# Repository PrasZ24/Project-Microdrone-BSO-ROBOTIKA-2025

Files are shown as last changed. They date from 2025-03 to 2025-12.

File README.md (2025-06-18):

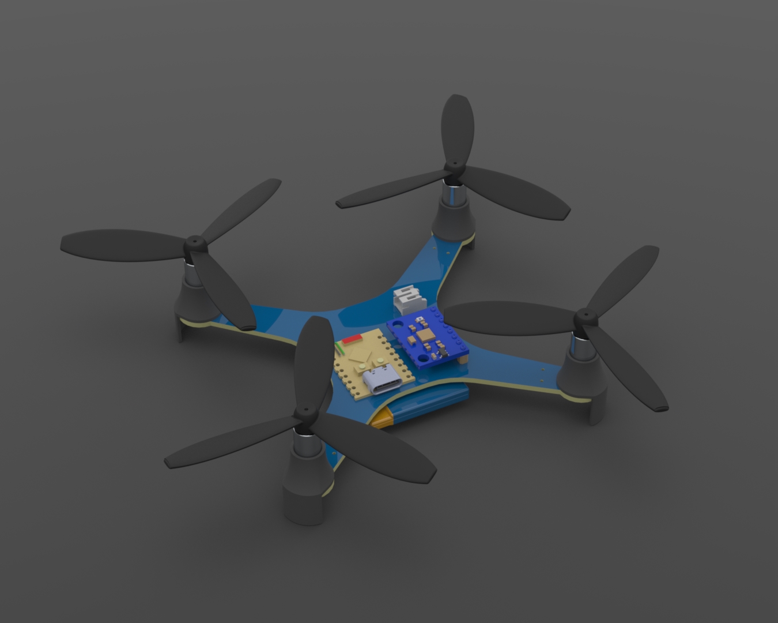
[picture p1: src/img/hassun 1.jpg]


# Project-AIRMINI (Aerial Intelligent Riset Microdrone Inovatif)-BSO-ROBOTIKA-2025
## Microdrone project by Research And Development BSO ROBOTIKA UIN Sunan Gunung Djati Bandung
Microdrone ini dirancang sebagai quadcopter compact dengan dimensi 130mm x 130mm, cocok untuk penerbangan rendah sekitar 10 meter di atas tanah. Dengan motor tipe "720" DC coreless, yang kecil dan efisien, dengan baling-baling yang bisa 2, 3, atau 4 bilah untuk fleksibilitas performa. Altitude diukur menggunakan sensor barometer, sementara stabilitas dikelola oleh IMU MPU6050, yang memastikan penerbangan stabil dengan kontrol PID, algoritma anti-windup, dan filter Kalman atau komplementer untuk data sensor yang akurat.

### Team list :
  - Prasetya Garda Kesumabangsa
  - Fikri Alif Hafiz
  - Muhammad Irsyad

Ini adalah repositori dari grup riset dan pengembangan BSO ROBOTIKA UIN Sunan Gunung Djati Bandung. Repositori ini akan berisikan catatan, hasil diskusi, code, desain mekanikal, desain elektrikal, skematik dan lain sebagainya dari hasil riset kami.

Status : Ongoing

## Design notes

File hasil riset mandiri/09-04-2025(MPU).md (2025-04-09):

**MPU-6050** itu adalah **sensor kecil** yang bisa mendeteksi:

1. **Gerakan (akselerasi)** – Misalnya seberapa cepat sensor itu digerakkan ke kiri, kanan, atas, atau bawah. MPU-6050 mengukur percepatan (bukan kecepatan).
2. **Putaran (rotasi/sudut)** – Misalnya kalo kita memiringkan atau memutar sensor ke arah tertentu.

Sensor ini penting untuk mikrodrone kita karena mikrodrone butuh tahu arah dan gerakan. Bisa dibilang ini kayak “indra keseimbangan” buat mikrodrone

Kalau digoyangin sensor ini, dia bisa tahu kamu gerakin ke mana, dan seberapa cepat gerakannya.

**catatan** : sensor MPU-6050 ini memiliki Sensor suhu, namun **bukan untuk mendeteksi suhu** lingkungan tetapi **f**ungsinya lebih ke mengkompensasi perubahan suhu internal sensor agar data akselerometer dan giroskop tetap akurat, karena sensor akselerator dan giroskop pada MPU-6050 itu sangat dipengaruhi oleh suhu.

Code membaca MPU6050 dengan Adafruit MPU6050: 

```arduino
// Basic demo for accelerometer readings from Adafruit MPU6050

#include <Adafruit_MPU6050.h>
#include <Adafruit_Sensor.h>
#include <Wire.h>

Adafruit_MPU6050 mpu;

void setup(void) {
  Serial.begin(115200);
  while (!Serial)
    delay(10); // will pause Zero, Leonardo, etc until serial console opens

  Serial.println("Adafruit MPU6050 test!");

  // Try to initialize!
  if (!mpu.begin()) {
    Serial.println("Failed to find MPU6050 chip");
    while (1) {
      delay(10);
    }
  }
  Serial.println("MPU6050 Found!");

  mpu.setAccelerometerRange(MPU6050_RANGE_8_G);
  Serial.print("Accelerometer range set to: ");
  switch (mpu.getAccelerometerRange()) {
  case MPU6050_RANGE_2_G:
    Serial.println("+-2G");
    break;
  case MPU6050_RANGE_4_G:
    Serial.println("+-4G");
    break;
  case MPU6050_RANGE_8_G:
    Serial.println("+-8G");
    break;
  case MPU6050_RANGE_16_G:
    Serial.println("+-16G");
    break;
  }
  mpu.setGyroRange(MPU6050_RANGE_500_DEG);
  Serial.print("Gyro range set to: ");
  switch (mpu.getGyroRange()) {
  case MPU6050_RANGE_250_DEG:
    Serial.println("+- 250 deg/s");
    break;
  case MPU6050_RANGE_500_DEG:
    Serial.println("+- 500 deg/s");
    break;
  case MPU6050_RANGE_1000_DEG:
    Serial.println("+- 1000 deg/s");
    break;
  case MPU6050_RANGE_2000_DEG:
    Serial.println("+- 2000 deg/s");
    break;
  }

  mpu.setFilterBandwidth(MPU6050_BAND_21_HZ);
  Serial.print("Filter bandwidth set to: ");
  switch (mpu.getFilterBandwidth()) {
  case MPU6050_BAND_260_HZ:
    Serial.println("260 Hz");
    break;
  case MPU6050_BAND_184_HZ:
    Serial.println("184 Hz");
    break;
  case MPU6050_BAND_94_HZ:
    Serial.println("94 Hz");
    break;
  case MPU6050_BAND_44_HZ:
    Serial.println("44 Hz");
    break;
  case MPU6050_BAND_21_HZ:
    Serial.println("21 Hz");
    break;
  case MPU6050_BAND_10_HZ:
    Serial.println("10 Hz");
    break;
  case MPU6050_BAND_5_HZ:
    Serial.println("5 Hz");
    break;
  }

  Serial.println("");
  delay(100);
}

void loop() {

  /* Get new sensor events with the readings */
  sensors_event_t a, g, temp;
  mpu.getEvent(&a, &g, &temp);

  /* Print out the values */
  Serial.print("Acceleration X: ");
  Serial.print(a.acceleration.x);
  Serial.print(", Y: ");
  Serial.print(a.acceleration.y);
  Serial.print(", Z: ");
  Serial.print(a.acceleration.z);
  Serial.println(" m/s^2");

  Serial.print("Rotation X: ");
  Serial.print(g.gyro.x);
  Serial.print(", Y: ");
  Serial.print(g.gyro.y);
  Serial.print(", Z: ");
  Serial.print(g.gyro.z);
  Serial.println(" rad/s");

  Serial.print("Temperature: ");
  Serial.print(temp.temperature);
  Serial.println(" degC");

  Serial.println("");
  delay(500);
}
```

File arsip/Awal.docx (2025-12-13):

- MCU = ESP32 C3 mini
- Micromotor DC = 720 ?
- Propoller = Menyusul
- Motor Driver = Mosfet
- Kontrol = Bluetooth / Wifi
- Sensor =

Sensor sudut : IMU MPU6050 -> MPU9250

Sensor ketinggian : Altitude (BMP 280) Sensor tekanan udara

- Chasis = PCB
- Baterai = lithium 3.7V

Motor driver dan regulator
IMU dan Barometer dan Filter
System Control
PID
Mekanis

Perakitan dan troubleshouting

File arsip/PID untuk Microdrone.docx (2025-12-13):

PID untuk Microdrone

Oleh : Departemen Riset dan Pengembangan ROBOTIKA UIN SGD

Microdrone berbeda dari drone biasanya dan justru lebih sulit untuk direalisasikan. Hal ini karena microdrone memiliki ukuran yang kecil, membatasi sumber daya yang dapat digunakan. Hal ini tentu saja berimbas pada kontroller yang digunakan pada drone. Perbedaan motor DC, propeller, panjang lengan, massa, baterai, serta titik keseimbangan drone akan mempengaruhi kontrol yang digunakan. Setidaknya, pada suatu drone dibutuhkan sebuah sistem kontrol PID.

A. Sistem Kontrol PID (Proportional-Integral-Derivate)

PID (Proportional-Integral-Derivative) adalah sebuah sistem kontrol yang bertujuan untuk mencapai sebuah setpoint (titik atau nilai yang ditentukan) secara cepat dengan menggunakan akumulasi dari propotional, integral dan derivative. Sistem kontrol PID merupakan sistem kontrol closed loop yang membutuhkan feedback (umpan balik) dari output. Pada drone, output yang digunakan merupakan pembacaan sensor gyroscope, accelerometer,dan Magnetometer yang akan dihitung menjadi sudut. Sehingga nantinya, output akan digunakan bersama dengan setpoint untuk menghitung nilai error yang akan menjadi umpan balik untuk sistem PID. Error dapat dihitung secara matematis dengan:

error(t)=setpoint(t)-output(t)

Error ini akan digunakan pada setiap komponen yang digunakan di PID dan error inilah yang memberitahu sistem apakah sistem sudah mencapai setpoint atau belum dan seberapa jauh kondisi sistem saat ini dengan setpoint yang diinginkan.

Agar lebih sistematis, PID dapat dibagi berdasarkan komponen-komponennya, yaitu:

a) Proportional (kesebandingan)

Merupakan komponen PID yang menghitung secara sebanding dengan nilai error dan konstanta atau gainnya. Secara matematis dapat dihitung:

proportional(t)=Gain_(Proportional) ×error(t)

Pada drone, proportional mengatur seberapa responsif drone terhadap error. Semakin besar gain proportional yang diberikan, semakin cepat drone menanggapi error. Dan semakin kecil gain proportional yang diberikan, drone akan semakin lambat menanggapi error. Nilai gain inilah yang akan diatur atau dituning sehingga menghasilkan perilaku drone yang tepat.

- Jika drone berosilasi terlalu cepat, berarti nilai gain nya terlalu besar.
- Jika drone tidak berosilasi atau bahkan tidak mampu mencapai setpoint, maka nilai gain nya terlalu kecil.
- Nilai gain yang baik adalah ketika drone berosilasi tidak terlalu cepat tetapi dapat mencapai (atau melebihi) setpoint. Terutama jika diberi gangguan.
b) Integral

Merupakan komponen PID yang mengakumulasi error statis pada drone yang tidak bisa diselesaikan oleh proportional. Misalnya, drone sudah berhasil stabil disudut 2° tetapi, karena nilai error tetap, proportional tidak dapat menambahkan atau mengurangi nilainya agar drone bisa mencapai sudut 0° (setpoint). Sehingga, integral diperlukan. Integral walaupun nilai errornya tetap, ia dapat bertambah terus nilainya seiring dengan waktu hingga drone mencapai setpoint. Secara matematis, integral dapat dituliskan :

integral(t)=Gain_(Integral) ×(∫_0^t error(τ) dτ)

Dalam rumus diatas variabel t menunjukkan waktu sekarang (saat ini), sedangkan τ hanyalah variabel untuk integrasi. Integral pada PID ditulis seperti pada persamaan diatas karena kita ingin menjumlahkan error dari waktu nol hingga waktu t, dan untuk menghindari kebingungan digunakan simbol τ sebagai penanda waktu yang “berjalan” di dalam integral, sementara t tetap dipakai sebagai batas atas (waktu sekarang).

Pada drone, jika semakin besar gainnya, error statis akan cepat hilang. Namun jika semakin kecil gainnya, error statis akan sulit hilang.

- Jika drone malah berosilasi, berarti nilai gain integral terlalu besar.
- Jika drone terlalu lambat untuk menghilangkan error statis atau mencapai setpoint, maka nilai gain integral terlalu kecil.
- Nilai gain integral yang baik adalah ketika sistem dapat menghilangkan error statis tanpa terjadi overshoot.
c) Derivative (turunan)

Merupakan komponen PID yang melihat seberapa cepat error berubah terhadap waktu dengan memafaatkan penurunan error terhadap waktu. Secara matematis dapat ditulis:

derivative(t)=Gain_(Derivative) ×(error(t)d/(dt))

Pada drone, derivative dapat mengatur atau meredam osilasi. Derivative dapat bertindak sebagai “rem” ketika drone sudah dekat dengan setpoint. Jika error berubah cepat (misalnya output sistem mendekati setpoint dengan laju tinggi), maka komponen derivative akan menghasilkan sinyal besar untuk mengurangi kecepatan perubahan tersebut. Namun, jika error berubah lambat atau konstan, komponen derivative hampir tidak memberikan kontribusi.

- Jika drone jadi tidak responsif, berarti nilai gain derivative terlalu besar.
- Jika drone tetap berosilasi kencang, berarti nilai gain derivative terlalu kecil.
- Nilai gain derivative yang tepat adalah ketika drone dapat merespon gangguan dan drone dapat stabil tanpa osilasi.

Sebagaimana yang disebutkan sebelumnya, PID adalah akumulasi dari komponen proportional, integral dan derivative. Sehingga, output dari masing-masing komponen tersebut dijumlahkan menjadi satu output. Secara matematis dapat ditulis sebagai berikut :

PID(t)=proportional(t)+integral(t)+derivative(t)

Output pid ini dapat langsung digunakan untuk mengontrol aktuator. Pada drone, output pid dapat langsung digunakan sebagai nilai PWM dan disesuaikan dengan kondisi drone. Tetapi, output PID ini hanya bisa digunakan untuk 1 axis saja. Sehingga jika ingin menstabilkan di 3 axis diperlukan 3 sistem kontrol PID.

Pada percobaan yang kami lakukan, sayangnya PID saja tidak cukup. Khususnya pada microdrone dengan panjang lengan yang relatif pendek. Lengan yang pendek ini menyebabkan momen inersia pada microdrone menjadi lebih kecil dan tidak memiliki keseimbangan “alami”.Hal ini mengakibatkan drone menjadi lebih agresif dan sulit untuk “tenang”. Sehingga, untuk mengatasi masalah tersebut, digunakan sistem kontrol PID yang lebih modern. Yaitu cascade PID.

B. Sistem Kontrol Cascade PID (PID Berurut)

Pada dasarnya cascade PID adalah loop PID biasa yang ditumpuk dua atau lebih secara berurut. Misalnya pada sistem paling sederhana dari cascade PID dengan dua loop saja. Yaiut outer loop dan inner loop. Dimana output dari outer loop akan menjadi setpoint dari inner loop. Cascade PID ini Lebih cepat merespons gangguan karena inner loop bisa mengoreksi lebih dulu sebelum error besar muncul di variabel utama atau di outer loop. Serta menjamin stabilitas yang lebih baik untuk sistem kompleks yang punya variabel turunan, noise yang tinggi, dan sistem yang sensitif atau agresif. Secara matematis, persamaan PID baik inner loop maupun outer loop sama. Yang membedakan ada pada nilai errornya. Error pada inner loop dihitung dengan :

error_(inner loop) (t)= output_(outer loop) (t)-

output_(inner loop) (t)

Barulah pada PID inner loop, outputnya digunakan untuk mengatur/mengontrol aktuator.

Pada drone, outer loop menggunakan umpan balik dari sudut atau kemiringan drone. Sedangkan untuk inner loopnya, menggunakan umpan balik dari kecepatan sudut drone. Sehingga, inner loop akan bereaksi sesuai dengan kecepatan perubahan sudut. Jika drone bergerak dari sudut 0° ke 30° dengan cepat, maka error pada inner loop akan besar juga. Memperbesar nilai output dan mengatasi perubahan cepat atau perubahan yang agresif dari drone. Sedangkan ketika perubahan sudut drone lambat, maka nilai error inner loop nya relatif lebih kecil, memungkinkan hanya output dari outer loop yang bekerja.

- Outer loop berfungsi untuk “mengejar” nilai setpoint.
- Inner loop berfungsi untuk mengatasi drone yang agresif sehingga outer loop dapat bekerja dengan lebih baik.
C. Penerapan PID pada program

Penerapan PID untuk microdrone ini dilakukan pada ESP32 C3 sehingga bahasa yang digunakan adalah CPP atau arduino. Sedangkan pada bahasa CPP tidak ada operasi integral ataupun turunan secara langsung. Tidak seperti pada Matlab ataupun python. Sehingga integral dan turunan dihitung dengan pendekatan diskrit. Untuk integral dapat menggunakan pendekatan dengan Euler Forward dan untuk turunannya menggunakan Backward Difference. Berikut cuplikan kodenya untuk PID Cascade pada axis roll :

// ===== Outer Loop (Angle PID) =====

double error_angle_roll, prevError_angle_roll = 0;

double integral_angle_roll = 0;

double kp_angle_roll = 5, ki_angle_roll = 0.001, kd_angle_roll = 0.01;

unsigned long lastTime_angle_roll;

float sampleTime_angle = 0.01; // 100 Hz

float rateTarget_roll = 0; // output → target laju (°/s)

// ===== Inner Loop (Rate PID) =====

double error_rate_roll, prevError_rate_roll = 0;

double integral_rate_roll = 0;

double kp_rate_roll = 1, ki_rate_roll = 0.01, kd_rate_roll = 0.04;

unsigned long lastTime_rate_roll;

float sampleTime_rate = 0.002; // 500 Hz

double integral_limit = 30; // batas integral anti-windup

// ===== Outer Loop: Angle Control =====

float hitungPIDAngleRoll(float angleY) {

unsigned long now = millis();

float dt = (now - lastTime_angle_roll) / 1000.0;

if (dt >= sampleTime_angle) {

float error = setPoint_roll - angleY;

float P = kp_angle_roll * error;

integral_angle_roll += error * dt;

// Anti-windup

if (integral_angle_roll > integral_limit) integral_angle_roll = integral_limit;

if (integral_angle_roll < -integral_limit) integral_angle_roll = -integral_limit;

float I = ki_angle_roll * integral_angle_roll;

float D = kd_angle_roll * ((error - prevError_angle_roll) / dt);

rateTarget_roll = P + I + D;

// Batas rate target

if (rateTarget_roll > 200) rateTarget_roll = 200;

if (rateTarget_roll < -200) rateTarget_roll = -200;

prevError_angle_roll = error;

lastTime_angle_roll = now;

}

return rateTarget_roll;

}

// ===== Inner Loop: Rate Control =====

void hitungPIDRateRoll(float gyroY, float rateTarget_roll) {

unsigned long now = millis();

float dt = (now - lastTime_rate_roll) / 1000.0;

if (dt >= sampleTime_rate) {

float error = rateTarget_roll - gyroY;

float P = kp_rate_roll * error;

integral_rate_roll += error * dt;

// Anti-windup

if (integral_rate_roll > integral_limit) integral_rate_roll = integral_limit;

if (integral_rate_roll < -integral_limit) integral_rate_roll = -integral_limit;

float I = ki_rate_roll * integral_rate_roll;

float D = kd_rate_roll * ((error - prevError_rate_roll) / dt);

pwmOut_roll = P + I + D;

if (pwmOut_roll > 200) pwmOut_roll = 200;

if (pwmOut_roll < -200) pwmOut_roll = -200;

prevError_rate_roll = error;

lastTime_rate_roll = now;

}

Agar lebih jelas, program akan dibahas perbaris.

// ===== Outer Loop: Angle Control =====

float hitungPIDAngleRoll(float angleY) {

Sintaks untuk membuat sebuah fungsi yang menghitung PID bagian outer loop atau yang menghitung dengan setpoint dari pengguna (dalam derajat) dan umpan balik sudut. Parameter didalam adalah untuk memasukan umpan balik sudut.

unsigned long now = millis();

Membuat variabel lokal bernama now dengan tipe data long. Unsigned menunjukan bahwa variabel tidak menerima data negatif. Kemudian variabel ini diisi oleh RTC dari ESP32 atau dapat dipanggil dengan fungsi millis(). Millis ini bekerja dengan menghitung seberapa lama (dalam mili detik) ESP32 menyala terhitung dari pertama kali dinyalakan.

float dt = (now - lastTime_angle_roll) /

1000.0;

Variabel dt dengan tipe data float adalah variabel yang menghitung jarak waktu antar loop per satuan detik. Variabel ini penting digunakan untuk integral maupun turunan.

if (dt >= sampleTime_angle) {

Pengkondisian untuk mengatur seberapa cepat loop setiap perhitungan PID nya atau bisa disebut sample rate nya. Nilai sampleTime dapat diatur tetapi direkomendasikan di 100Hz atau 0.001.

float error = setPoint_roll - angleY;

Menghitung nilai error dengan set point dan sudut.

float P = kp_angle_roll * error;

Menghitung komponen PID yang pertama yaitu proportional sesuai dengan yang ada pada rumus umumnya.

integral_angle_roll += error * dt;

Menghitung integral (bukan hasil akhir) dengan Euler Forward. Dimana agar variabel integral_angle_roll tidak kembali ke nilai 0 atau reset, maka variabel tersebut harus dideklarasikan sebagai variabel global. Hal ini penting karena pada pendekatan Euler Forward, menggunakan persamaan :

integral(t)=integral(t-1)+error(t)*dt

Pada rumus tersebut, dibutuhkan nilai integral sebelumnya. Sehingga nilai integral sebelumnya harus tetap ada. Selain itu, pada Euler Forward nilai error saat ini dkalikan dengan waktu sampling antar loop dan ditambahkan nilai integral sebelumnya.

if (integral_angle_roll > integral_limit)

integral_angle_roll = integral_limit;

Pengkondisian untuk logika anti-wind up integral. Logika ini berfungsi untuk membatasi nilai integral. Karena nilai integral terikat pada nilai sebelumnya, sehingga jika tidak dibatasi oleh variabel integral_limit maka nantinya nilai integral akan menjadi terlalu besar dan akan sulit untuk turun lagi jika ada perubahan yang mendadak dan cepat. Pada kondisi ini, jika nilai integralnya melebihi dari batas yang diterapkan, program akan memberikan nilai batasnya ke variabel integral.

if (integral_angle_roll < -

integral_limit) integral_angle_roll = -integral_limit;

Baris ini adalah pengkondisian untuk logika anti-wind up integral juga. Tetapi untuk bagian negatifnya atau ketika perhitungan integral menghasilkan negatif tetap harus dibatasi.

float I = ki_angle_roll *

integral_angle_roll;

Menghitung nilai integral yang dikalikan dengan gain dari integral.

float D = kd_angle_roll * ((error –

prevError_angle_roll) / dt);

Menghitung komponen terakhir pada PID yaitu derivative atau turunan menggunakan Backward Different. Turunan ini dihitung dengan persamaan :

derivative(t)=(error(t)-error(t-1))/(dt)

Dimana, setelah rumus diatas dihitung. Hasilnya dikalikan dengan gain dari derivative untuk tuningnya.

rateTarget_roll = P + I + D;

Sesuai dengan rumus umum, komponen-komponen PID dijumlahkan dan karena ini adalah outer loop. Maka outputnya dianggap sebagai setpoint untuk inner loop atau rate target.

if (rateTarget_roll > 200)

rateTarget_roll = 200;

Pengkondisian untuk membatasi output dari PID agar tidak terlalu besar dan mengganggu throttle. Pada contoh ini menggunakan PWM dengan resolusi 8 bit atau dari 0 hingga 255. Sehingga agar terdapat “nafas” untuk throttle output PID dibatasi hingga 200 atau dapat disesuaikan tergantung kondisi dari drone.

Walaupun pada outer loop outputnya digunakan untuk setpoint inner loop, tetap harus dibatasi. Mengingat setpoint memiliki peran yang besar dalam menentukan error.

if (rateTarget_roll < -200)

rateTarget_roll = -200;

Pengkondisian untuk membatasi output PID outer loop yang membatasi bagian negatif jika output yang dikeluarkan oleh perhitungan menghasilkan nilai negatif.

prevError_angle_roll = error;

Variabel yang berfungsi menyimpan nilai error sebelumnya. Variabel ini harus dideklarasikan sebagai variabel global agar nilainya tidak kembali ke nilai default.

lastTime_angle_roll = now;

Variabel yang menyimpan nilai waktu setelah perhitungan PID selesai. Variabel ini juga harus dideklarasikan sebagai variabel global. Bagian ini digunakan dalam perhitungan dt.

return rateTarget_roll;

Karena fungsi didefinisikan sebagai fungsi bertipe float. Sehingga perlu ada nilai yang dikembalikan. Sehingga sebagai output atau pengembalian yang diharapkan dari fungsi ini adalah output akhir dari PID. Selain itu, dengan menggunakan pengembalian seperti ini memungkinkan fungsi dijalankan dalam parameter fungsi lain. Seperti pada fungsi inner loop nanti.

// ===== Inner Loop: Rate Control =====

void hitungPIDRateRoll(float gyroY, float rateTarget_roll) {

Mendefinisikan sebuah fungsi untuk menghitung PID pada inner loop. Didalamnya ada parameter untuk umpan balik yang menggunakan gyro pada axis roll dan parameter untuk setpoint dari perhitungan outer PID sebelumnya.

Untuk bagian perhitungan PID lainnya sama saja. Namun, perhitungan errornya menggunakan setpoint dari output outer loop dan menggunakan data dari pembacaan sensor gyroscope dan bukan sudut.

Selain itu, yang membedakan fungsi pada inner loop dengan outer loop adalah pada akhir fungsi. Dimana karena inner loop bertipe void, maka tidak ada nilai yang dikembalikan. Dan output PID akhir tersimpan di variabel global dan siap digunakan.

Walaupun PID pada dasarnya adalah sistem kontrol yang paling umum digunakan untuk menstabilkan drone, pada kasus-kasus tertentu khususnya pada microdrone PID saja tidak cukup. Dibutuhkan sistem kontrol cascade PID yang memiliki kinerja lebih baik karena menggunakan dua PID secara berurutan.

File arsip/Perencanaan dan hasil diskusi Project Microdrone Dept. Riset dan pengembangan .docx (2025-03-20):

Rev 1.0

10/05/25

Rev 1.1

13/05/25

Identifikasi Kebutuhan

- Drone quadcopter;
- Terbang dengan ketinggian rendah dan stabil;
- Kontrol NRF24l01 SMD atau bluetooth;
- Penggunaan komponen seminim dan sesederhana mungkin;

Analisis Kebutuhan

- Drone quadcopter, dimensi maksimal 130mm x 130mm. Dengan 4 micromotor dc 720, propeller 4, 3 atau 2 bilah dan baterai lithium (menyesuaikan).
- Terbang dengan ketinggian rendah, yaitu sekitar 10m diatas permukaan tanah. Ketinggian drone diketahui dengan sensor barometer[1]. Dan stabilitas drone diatur menggunakan IMU MPU6050[2].
- Menerapkan PID, anti windup algorithm, dan kalman atau complementary filter.
- Kontrol drone dikendalikan oleh manusia (manual). Baik menggunakan remote control nrf24l01 atau remote control berbasis bluetooth (misal ps3).
- Untuk mencapai ukuran yang seminim mungkin dan desain yang kompleks. Dibutuhkan komponen-komponen SMD. Untuk regulator dan mosfet membutuhkan arus maksimal yang besar (diatas 2.5A).

Apa saja yang dibutuhkan untuk membangun drone?

- MCU = ESP32 C3 mini
- Micromotor DC = 720 ?
- Propoller = Menyusul
- Motor Driver = Mosfet
- Kontrol = Bluetooth / Wifi
- Sensor =

Sensor sudut : IMU MPU6050 -> MPU9250

Sensor ketinggian : Altitude (BMP 280) Sensor tekanan udara

- Chasis = PCB
- Baterai = lithium 3.7V

Alur riset :

- Motor driver dan regulator
- System Control (Remote Control)
- Dasar-dasar PID
- Data processing : IMU dan Barometer serta Filter nya
- Mekanikal
- Perancangan, Perakitan dan troubleshouting

Ref :

[1] https://www.hackster.io/SurtrTech/bmp280-measure-temperature-pressure-and-altitude-e1c857

[2] https://electronoobs.com/eng_robotica_tut9_2_2.php

[3] https://docs.espressif.com/projects/espressif-esp-drone/en/latest/gettingstarted.html

[4] https://youtu.be/dMRDzicSvXk?si=LSDi5mkgHMitzkxS

[5] https://www.youtube.com/watch?v=Sa6EslOHsI0&t=210s

[6] Muhammad Dzaki Al Haidar, Elshinta Adelia Ryzty, Rizky Ramadhan,Theodorich Brian Putra Marpaung, Ariq Rifki Kurniawan, Ardy Seto Priambodo. “Pengembangan Mini Drone Berbasis ESP32 dengan Roll dan Pitch ControlMenggunakan Algoritma PID.” Daerah Istimewa Yogyakarta, vol. 18, https://electrician.unila.ac.id/index.php/ojs/article/view/2597/559.

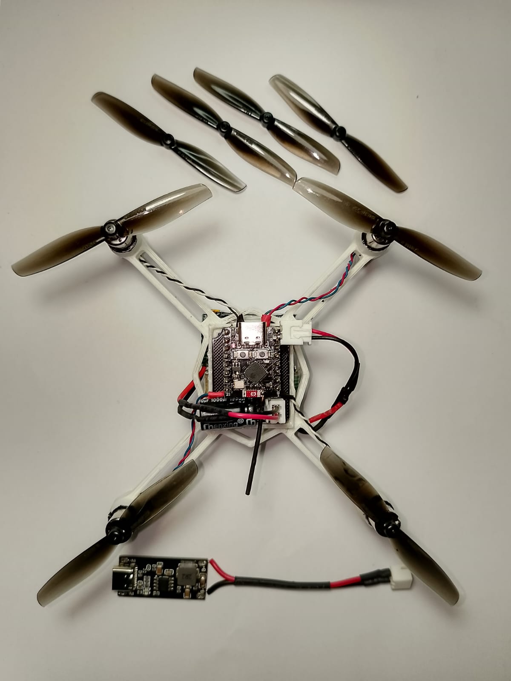
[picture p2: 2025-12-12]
dokumentasi/IMG-20251211-WA0007.jpg

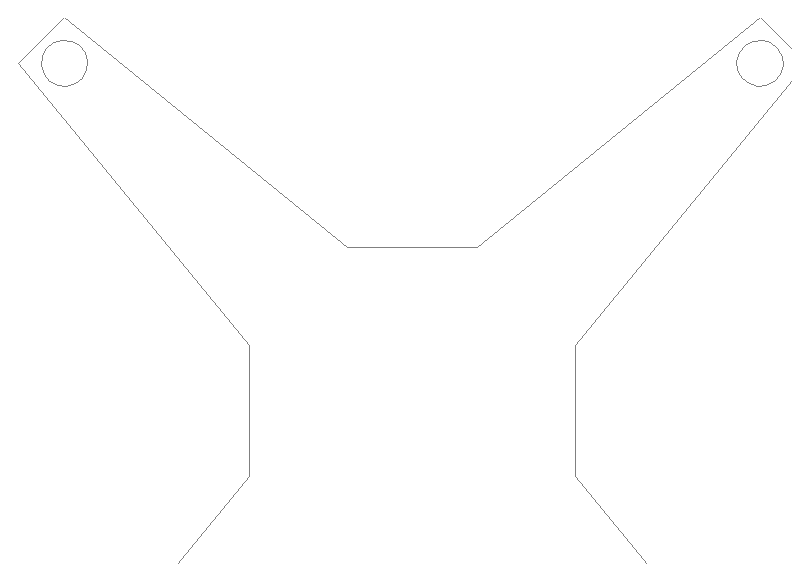
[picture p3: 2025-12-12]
arsip/3d and file/Drone_pcb.PNG

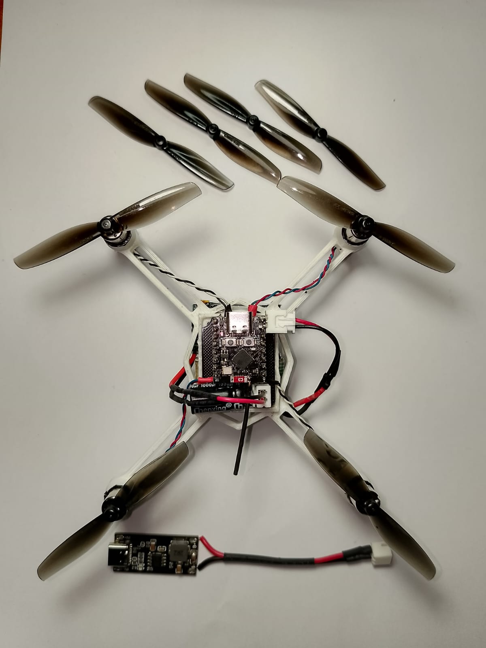
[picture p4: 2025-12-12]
dokumentasi/IMG-20251211-WA0010.jpg

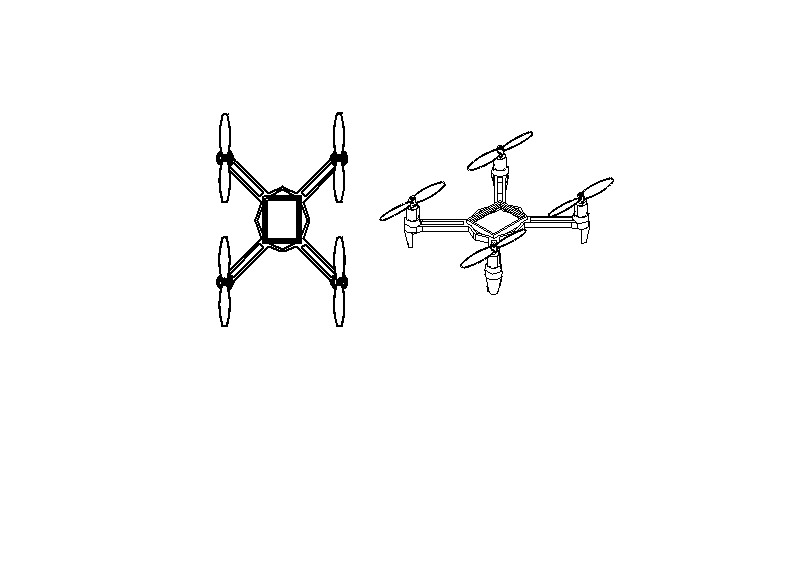
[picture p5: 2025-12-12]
arsip/3d and file/drone3.JPG

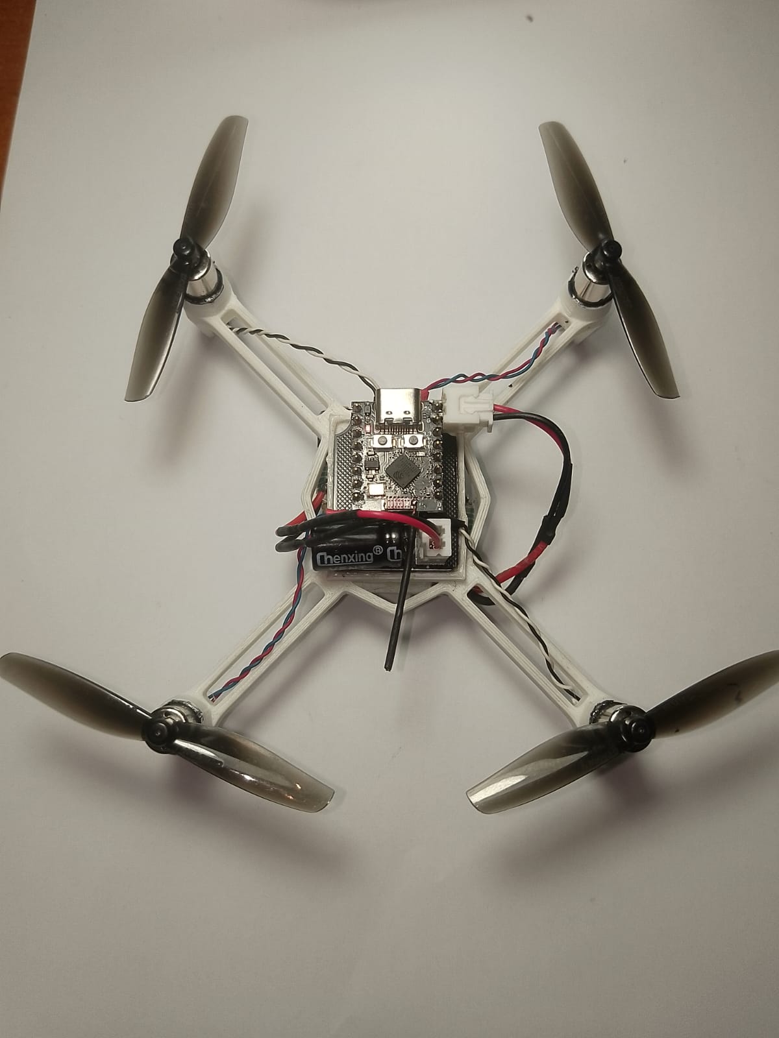
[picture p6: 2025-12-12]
dokumentasi/IMG-20251211-WA0008.jpg

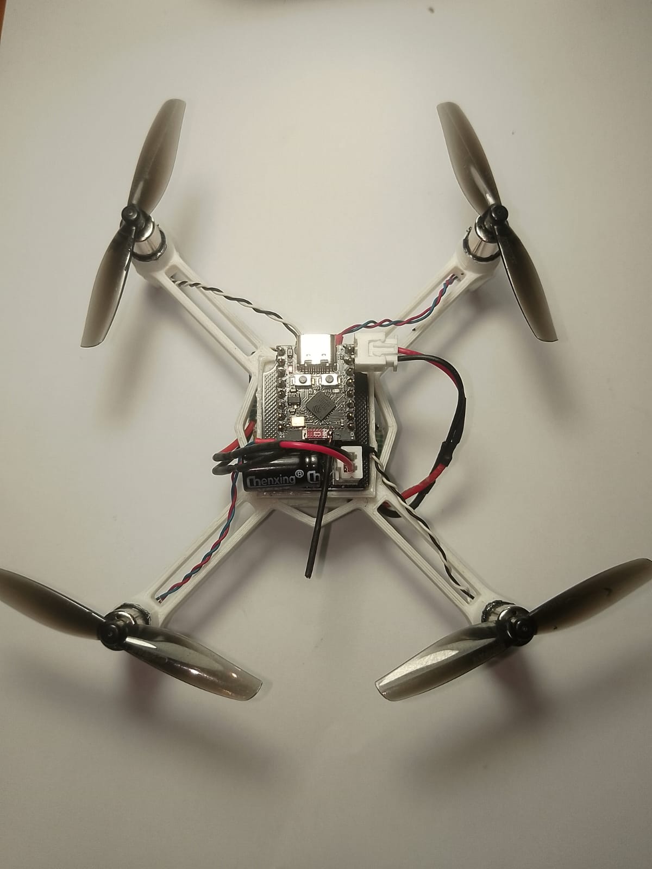
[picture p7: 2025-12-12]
dokumentasi/IMG-20251211-WA0009.jpg

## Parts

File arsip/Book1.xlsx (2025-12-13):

No | Nama | qty | harga | total | link
1 | Micromotor 716 | 4 | Rp 12000.00 | Rp 48000.00 | https://shopee.co.id/Hollow-Cup-Motor-Dinamo-Pesawat-Drone-Helikopter-7mm-714-716-720-i.53753550.21281371067
2 | Baterai | 1 | Rp 150000.00 | Rp 150000.00 | https://shopee.co.id/Gaoneng-GNB-2S-850mah-60C-120C-LiHV-Battery-7.6V-Socket-XT30-i.21348567.25813407479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
3 | propeller | 1 | Rp 40000.00 | Rp 40000.00 | https://shopee.co.id/product/991860709/28727072370?d_id=f3d39&uls_trackid=53qdgslt00rn
4 | Charger | 1 | Rp 40000.00 | Rp 40000.00
5 | 3d print chasis | 1 | Rp 20000.00 | Rp 20000.00
Total |  |  |  | Rp 298000.00

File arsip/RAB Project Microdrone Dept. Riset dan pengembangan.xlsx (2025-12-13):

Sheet: RAB Batch 1
RAB Project Microdrone
No. | Nama @jumlah | Harga | Link
1 | ESP32 C3 Super Mini @1 | Rp 48000.00 | esp32 (https://shopee.co.id/ESP32-C3-RISC-V-Super-Mini-Development-Board-WiFi-Bluetooth-5.0-ESP8266-Type-C-i.65450634.28022146930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) | Rp 163000.00 | Tidak dibeli
2 | MPU9250 + bmp280 @1 | Rp 115000.00 | MPU9250+BMP280 (https://shopee.co.id/(Ready-Stock)-GY-91-MPU9250-BMP280-10DOF-Acceleration-Gyroscope-Compass-Altimeter-Altitude-9-Axis-Sensor-Module-i.1385560436.28870693350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) |  | Dibeli
3 | Micromotor 720 @4 | Rp 40000.00 | 720 (https://www.tokopedia.com/cncstorebandung/micro-small-motor-dc-720-46000rpm-3-7v-high-torque-for-drone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)
4 | AO3400 @10 | Rp 5000.00 | A03400 (https://shopee.co.id/10x-MOSFET-AO3400-A09T-SOT-23-30V-5.8A-Transistor-Mosfet-AO-3400-AO3400A-SMD-SMT-1-N-Channel-i.65450634.28316152332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)
5 | 10k SMD 0805 @25 | Rp 3000.00 | Res 10k (https://shopee.co.id/25pcs-YAGEO-Resistor-Taiwan-YAGEO-0805-SMD-SMT-1-0R1-2K2-4K7-5K1-10K-15K-27K-47K-100K-Ohm-4.7K-Ohm-Chip-Resistor-i.65450634.26812843603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)
6 | 220 SMD 0805 @25 | Rp 3000.00 | Res 220 (https://shopee.co.id/25pcs-YAGEO-Resistor-Taiwan-YAGEO-0805-SMD-SMT-1-10R-100R-220R-330R-510R-1K-1K2-10-Ohm-1.2K-Ohm-Chip-Resistor-i.65450634.26862847127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)
7 | RS2M SMA FR207 Diode @5 | Rp 3000.00 | Diode (https://shopee.co.id/5pcs-Diode-RS2M-SMA-FR207-Diode-SMD-2A-1000V-Dioda-RS2M-FR207-i.65450634.23739158700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)
8 | Baterai 3.7v 650mAh @2 | Rp 100000.00 | battery (https://www.tokopedia.com/jslbejoshop/baterai-lithium-li-ion-mini-portable-3-7-v-600-mah-type-2)
9 | konektor jst siku @5 | Rp 1000.00 | JST (https://shopee.co.id/2P-Right-Angle-JST-2-Pin-XH2.54-Socket-Bengkok-2.54mm-Male-PCB-Connect-i.421203311.26016769686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)
10 | 7333A @1 | Rp 3000.00 | 7333A (https://shopee.co.id/HT-7333-7333A-IC-LDO-Low-Consumption-3.3V-3.3-V-Voltage-Regulator-i.29614947.14697538373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)
11 | Cetak PCB Spectra | Rp 310000.00 | JLPCB (https://cart.jlcpcb.com/quote?orderType=1&stencilLayer=2&stencilWidth=130&stencilLength=130&stencilCounts=5)
12 | Propeller @4 | Rp 15000.00 | 55mm Propeller (https://shopee.co.id/4pcs-Blade-Propeller-55mm-Baling-baling-Mini-Quadcopter-Drone-Hubsan-55x8mm-i.292092948.16288485252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)
13 | Stik PS3 | Rp 50000.00 | -
14 | 3D Print | Rp 20000.00 | 3D (https://shopee.co.id/Cetak-3D-Print-Dimensi-PLA--i.682252899.13493017350)
Total |  | Rp 716000.00
 |  |  |  |  |  | Ver 1 : 12/05/25
RAB Project Microdrone |  |  |  |  |  | Ver 2 : 13/05/25
No. | Nama @jumlah | Harga | Link |  |  | Ver 3 : 19/05/25 | Mengganti sensor MPU6250 dan BMP280 dengan MPU9250+BMP280
1 | Baterai 1000mAh | Rp 35800.00 | baterai 1000mah (https://shopee.co.id/-TOYSHOUSE-Baterai-Li-Po-3.7V-1000mAh-902540-untuk-Drone-Mainan-RC-(-HANYA-BATERAI-SAJA-TIDAK-DENGAN-CHARGERAN-NYA-)-i.996281136.43166094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) |  |  | Ver 4 : 29/05/25 | Menambahkan prioritas RAB untuk pencairan 1 april
2 | Gemfan 65mm propeller @8 | Rp 31700.00 | Propeller 65mm (https://shopee.co.id/4-Pair-Gemfan-65mmS-1mm-Shaft-65mm-Propeller-2.5-Inch-Clear-Black-i.991860709.28077251166) |  |  | Ver 5 : 19/11/25 | Update yang dibeli di pencairan batch 1
3 | Micromomtor 8520 @4 | Rp 101400.00 | 8520 (https://shopee.co.id/Dinamo-Motor-Drone-Coreless-8520-CW-CCW-8.5x20mm-for-Brushed-Micro-Mini-High-Speed-Quadcopter-Engine-i.8944057.24227476952)
Total |  | Rp 168900.00

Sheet: RAB Batch 2
RAB Project Microdrone (PCB Controller)
No. | Nama @jumlah | Harga | Link
1 | AO3400 Mosfet @4 | Rp 2000.00
2 | Resistor 1k6 @4 | Rp 1500.00
3 | ESP32 C3 Super Mini @1 | Rp 46000.00 |  | Rp 76000.00 | Berpotensi ditukar dengan barang yang sama di sekre
4 | MPU6050 @1 | Rp 30000.00
5 | JST @1 | Rp 500.00
6 | Ceramic Capacitor 10uF @1 | Rp 500.00
7 | PCB @1 | Rp 50000.00
8 | Res 10k @1 | Rp 500.00
Total |  | Rp 131000.00
RAB Project Microdrone
No. | Nama @jumlah | Harga | Link
1 | Baterai 300mAh @1 | Rp 27000.00 | Baterai 300mAh (https://shopee.co.id/Battery-Batere-Baterai-Lipo-1S-3.7V-3.7Volt-150mAh-25C-Syma-JST-Losi-2pin-gepeng-eachine-i.38108753.20775968108)
2 | Charger IP2312 @1 | Rp 10000.00 | Charger (https://shopee.co.id/Quick-Fast-Charging-Board-IP2312-CC-CV-Mode-5V-To-4.2V-Type-C-i.65450634.13396087860)
3 | Wadah 22x22cm@1 | Rp 17000.00 | Wadah (https://shopee.co.id/Kotak-Serbaguna-Viola-Tempat-Kue-Lapis-Bahan-Berkualitas-Food-Grade-i.272580400.5842540963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)
4 | Busa 25x25x4cm @1 | Rp 12000.00 | Busa (https://shopee.co.id/Busa-Royal-Foam-Hitam-Super-Lembaran-Busa-Packing-Paking-Hitam-High-Density-Packaging-Foam-Ukuran-25x25cm-i.73253976.27428820956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)
Total |  | Rp 66000.00
Total Pengajuan |  | Rp 197000.00
 | Total Pengajuan jika ada penukaran barang | Rp 121000.00

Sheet: Laporan Keuangan
Laporan Keuangan Microdrone
No | Keterangan | Kredit | Debit | Total
1 | Pencairan Batch 1 | Rp 318999.00 |  | Rp 318999.00
2 | ESP32 C3 Super Mini @1 |  | -Rp 48000.00 | Rp 270999.00
3 | MPU9250 + bmp280 @1 |  | -Rp 115000.00 | Rp 155999.00
4 | Baterai 1000mAh |  | -Rp 35800.00 | Rp 120199.00
5 | Gemfan 65mm propeller @8 |  | -Rp 31700.00 | Rp 88499.00
6 | Micromomtor 8520 @4 |  | -Rp 101400.00 | -Rp 12901.00
7
8
9
10

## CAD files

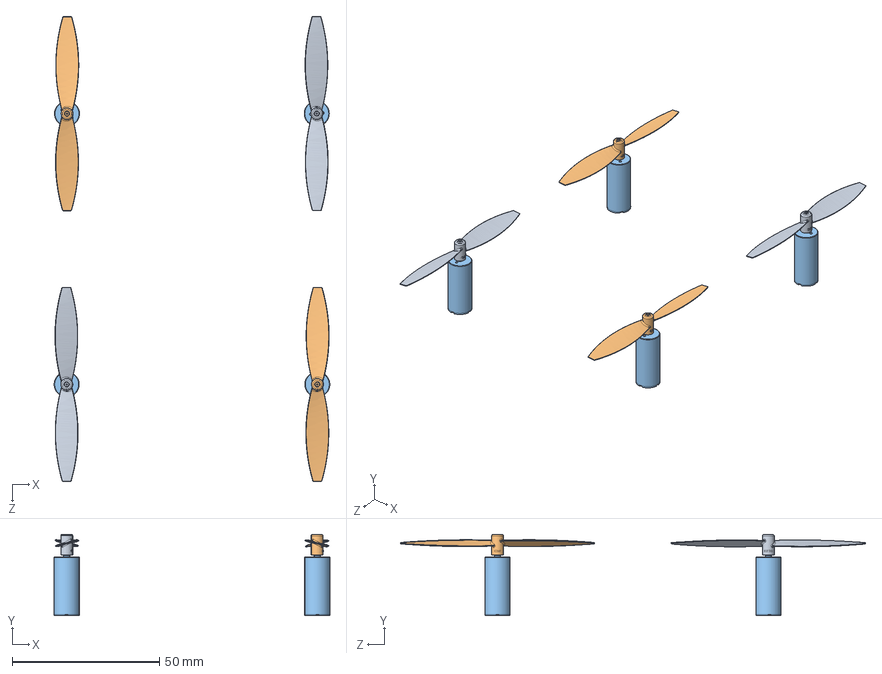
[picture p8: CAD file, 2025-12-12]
arsip/3d and file/drone3.SLDASM
93.7 x 27.7 x 158.0 mm
8520 micromotor dc x 4
helice-cw-65mm x 2
helice-ccw-65mm x 2

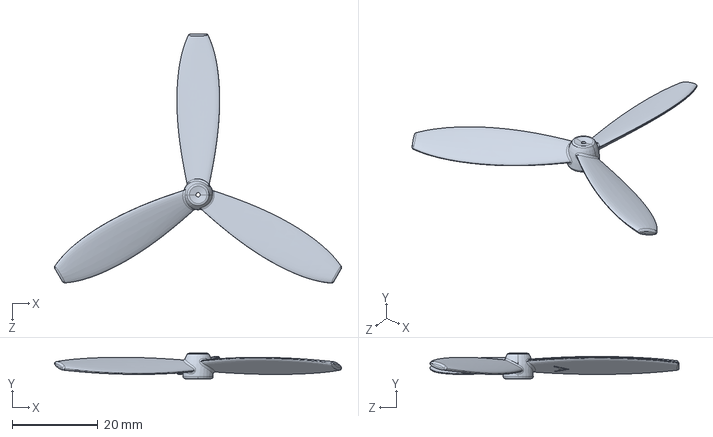
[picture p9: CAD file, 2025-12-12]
arsip/3d and file/Propeller_A.SLDPRT
66.8 x 5.94 x 58.1 mm

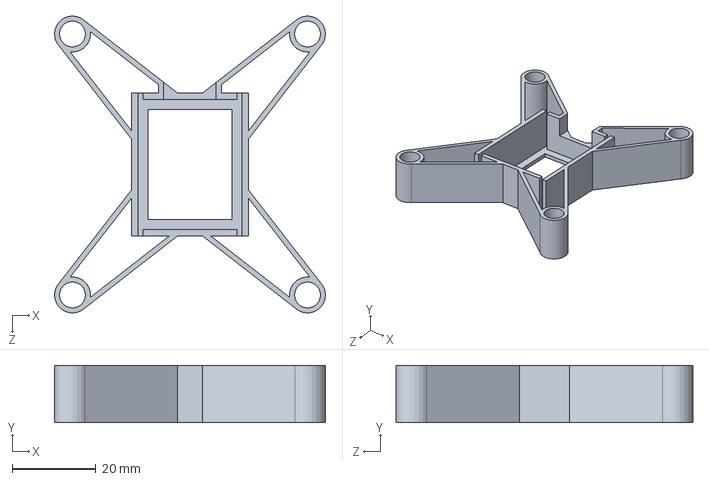
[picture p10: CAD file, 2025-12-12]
arsip/3d and file/USFUR.SLDPRT
64.7 x 13.7 x 70.9 mm

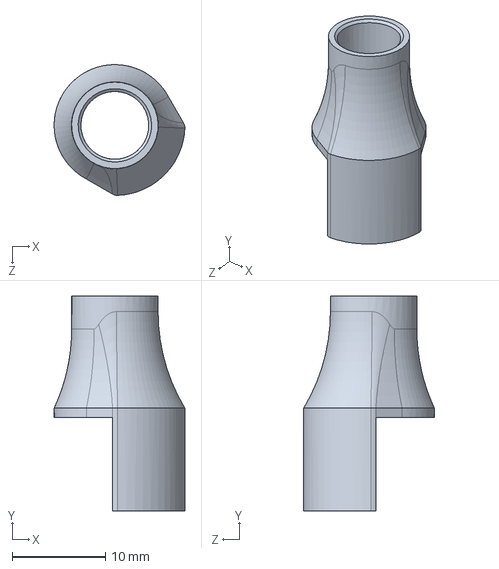
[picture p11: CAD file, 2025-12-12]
arsip/3d and file/drone motor holder hassun 1.SLDPRT
14.0 x 23.0 x 14.0 mm

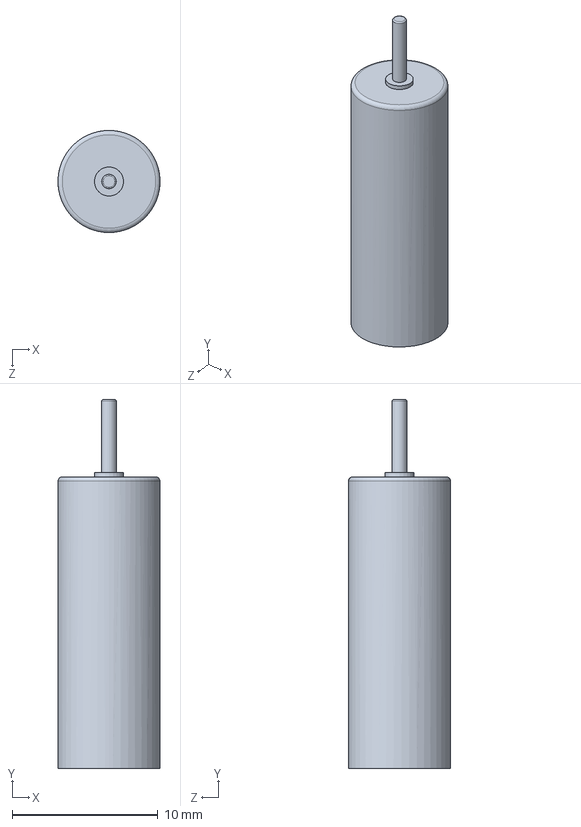
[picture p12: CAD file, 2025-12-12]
arsip/3d and file/motor dc 720.SLDPRT
6.99 x 25.3 x 7.00 mm

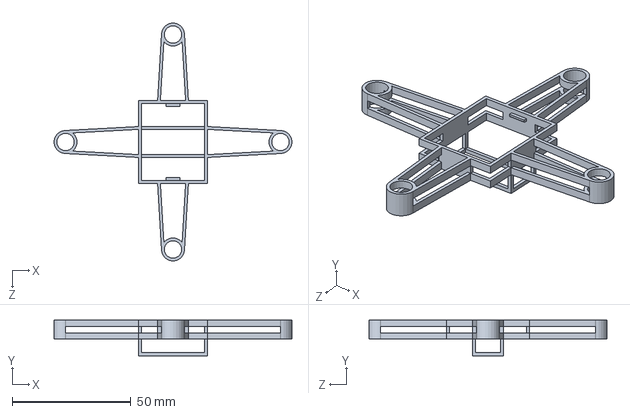
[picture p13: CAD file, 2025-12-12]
arsip/3d and file/drone_+.SLDPRT
100.1 x 15.0 x 100.1 mm

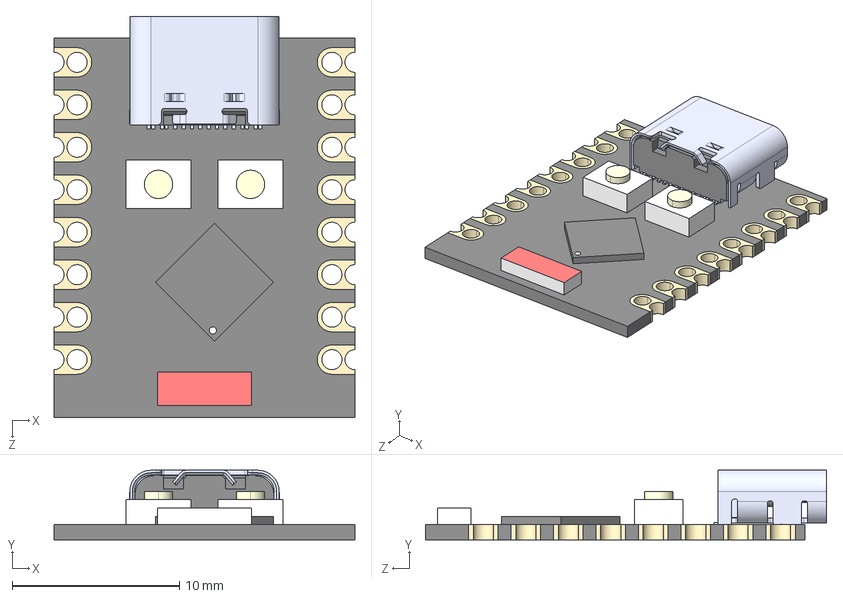
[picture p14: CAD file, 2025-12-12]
arsip/3d and file/ESP32-C3 SuperMini_TH--3DModel-STEP-56544.STEP
18.0 x 4.16 x 24.0 mm
Board c3mini
USB C
components (other)^ESP32-C3 SuperMini

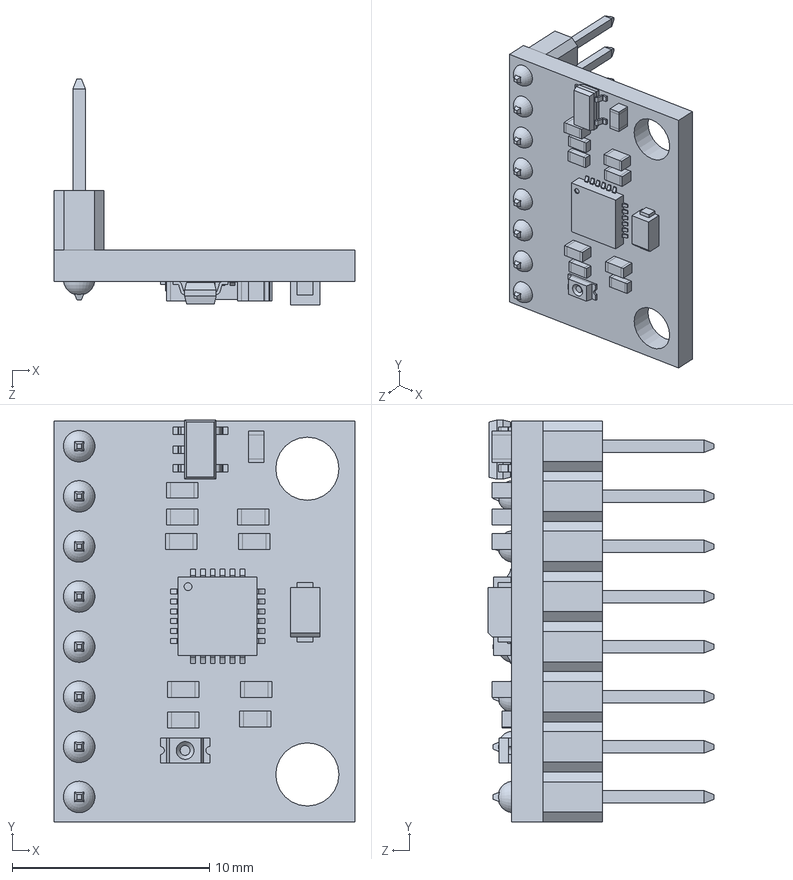
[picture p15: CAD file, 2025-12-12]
arsip/3d and file/MPU6050 Module.SLDPRT
15.2 x 20.4 x 11.5 mm

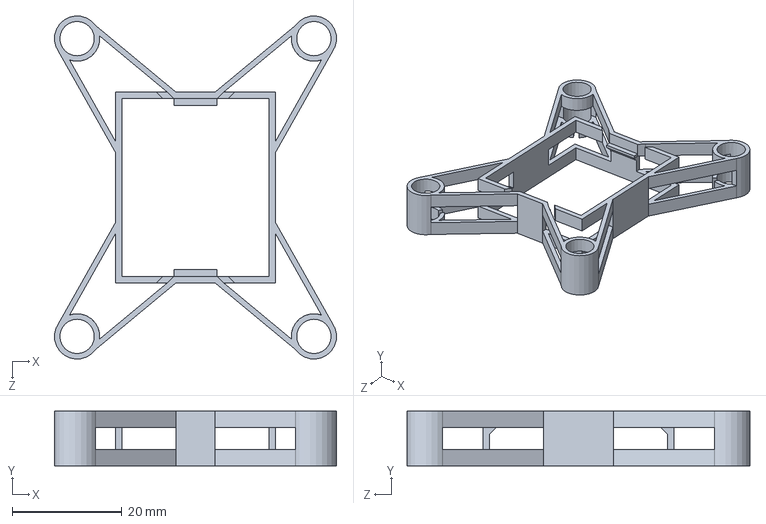
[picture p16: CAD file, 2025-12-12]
arsip/3d and file/USFUR2.1.SLDPRT
51.3 x 10.0 x 62.4 mm

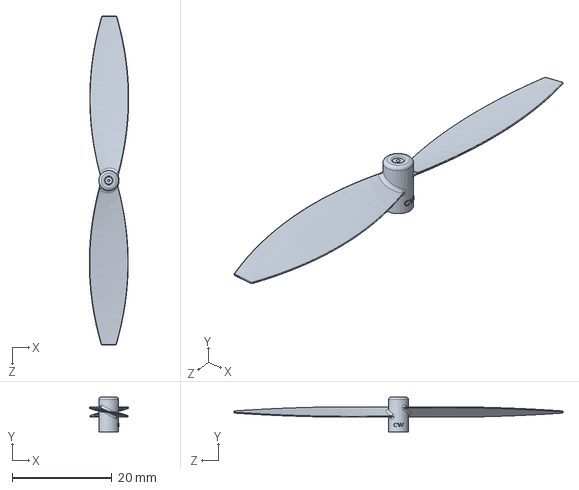
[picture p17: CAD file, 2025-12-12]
arsip/3d and file/helice-cw-65mm.SLDPRT
7.89 x 7.00 x 66.0 mm

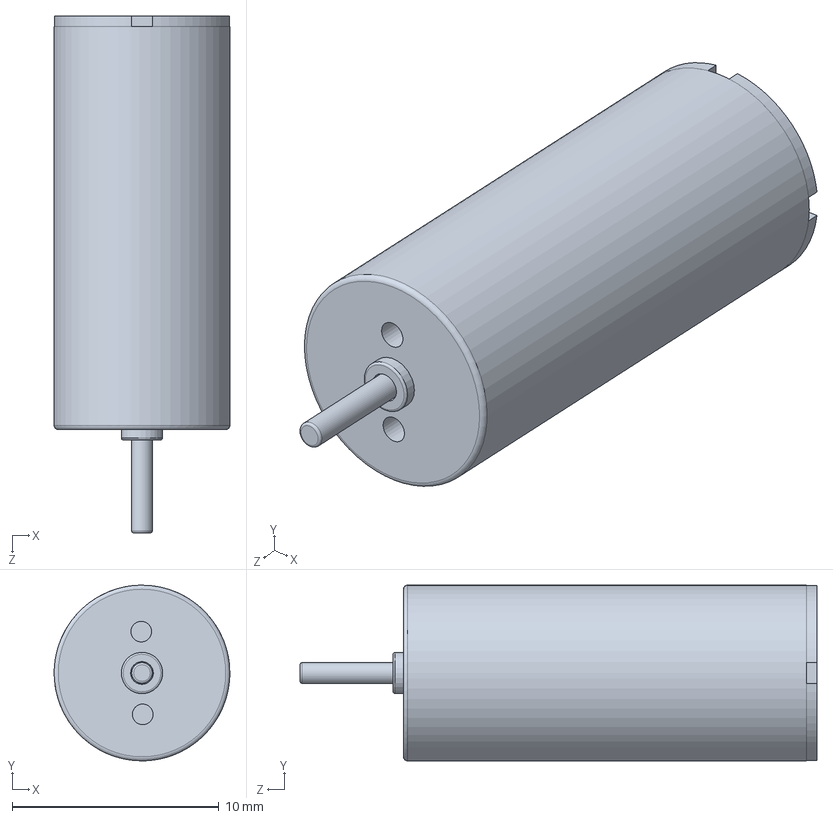
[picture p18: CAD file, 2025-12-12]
arsip/3d and file/8520 micromotor dc.SLDPRT
8.50 x 8.50 x 25.0 mm

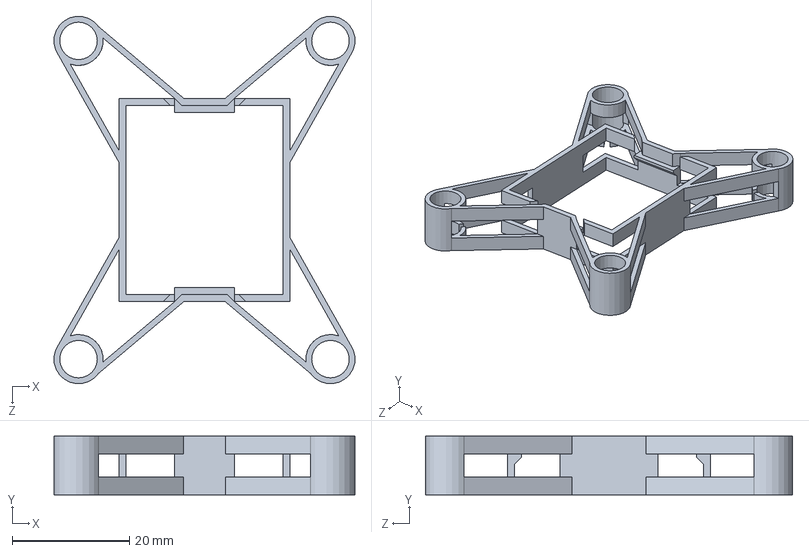
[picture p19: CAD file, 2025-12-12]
arsip/3d and file/USFUR2.SLDPRT
51.3 x 10.0 x 62.6 mm

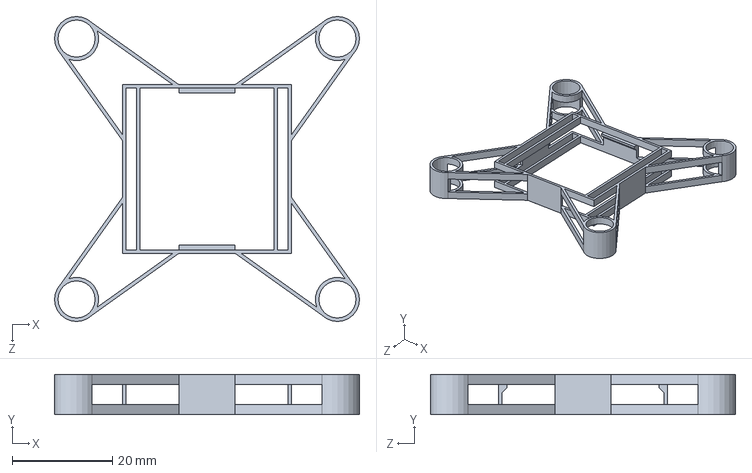
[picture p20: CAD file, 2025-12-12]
arsip/3d and file/USFUR3.SLDPRT
60.8 x 8.00 x 60.8 mm

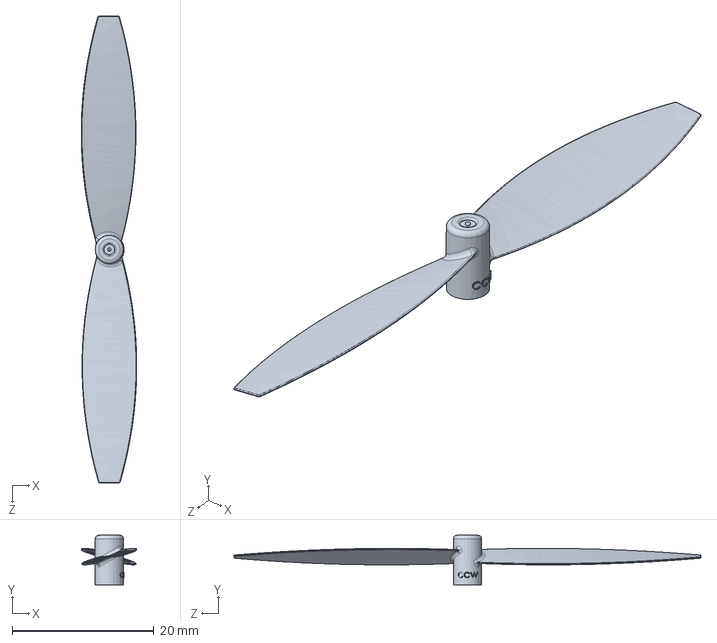
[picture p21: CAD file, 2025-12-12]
arsip/3d and file/helice-ccw-65mm.SLDPRT
7.84 x 7.00 x 66.0 mm

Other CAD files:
arsip/3d and file/drone_+_mountA.SLDPRT
arsip/3d and file/Drone_pcb.SLDPRT
arsip/3d and file/Drone holder.SLDPRT
arsip/3d and file/ESP32-C3 supermini v5.step
arsip/3d and file/402530, LiPo battery 300 mAh.SLDPRT
arsip/3d and file/Drone holder.3MF
arsip/3d and file/ESP32-C3 SuperMini_TH--3DModel-STEP-56544.SLDPRT
arsip/3d and file/ESP32-C3 supermini v5.SLDPRT
arsip/3d and file/Propeller_B.SLDPRT
arsip/3d and file/drone motor holder hassun 1 - Copy (2).3MF
arsip/3d and file/drone motor holder hassun 1 - Copy (3).3MF
arsip/3d and file/drone motor holder hassun 1 - Copy.3MF
arsip/3d and file/drone motor holder hassun 1.3MF
arsip/3d and file/drone3.SLDDRW
arsip/3d and file/drone3.SLDPRT
arsip/3d and file/drone_+.STL
arsip/3d and file/drone_+_mountA.STL

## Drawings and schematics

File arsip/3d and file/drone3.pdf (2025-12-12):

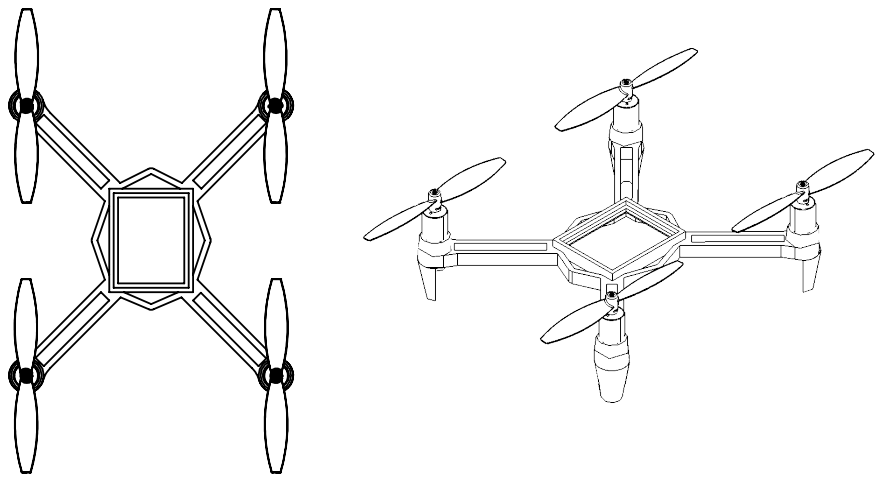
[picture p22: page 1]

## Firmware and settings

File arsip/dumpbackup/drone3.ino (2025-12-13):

#include <MPU6050_light.h>
#include <PID_v1.h>
#include <pid_tuner.h>

pid_tuner tuner;
MPU6050 sensor_mpu(Wire);

// ===== Trim =====
double u1 = 0;
double u2 = 10;
double u3 = 10;
double u4 = 0;
int batas = 0;

// ===== Input sensor =====
double angleY = 0;  // sudut (derajat) dari IMU
double gyroY = 0;   // laju putar (°/s) dari gyro
double angleX = 0;  // sudut (derajat) dari IMU
double gyroX = 0;   // laju putar (°/s) dari gyro

// ===== Setpoint =====
double setPoint_roll = 0;  // target sudut (derajat)
double setPoint_pitch = 0;
int throttle = 0;  // throttle utama (untuk motor)

// ===== Yaw Control =====
double setPoint_yaw = 0;  // target yaw rate (°/s), bisa dari remote
double error_rate_yaw, prevError_rate_yaw = 0;
double integral_rate_yaw = 0;
float kp_rate_yaw = 1.1, ki_rate_yaw = 0.1, kd_rate_yaw = 0.;
unsigned long lastTime_rate_yaw;
double pwmOut_yaw = 0;


// ===== Outer Loop (Angle PID) =====
double error_angle_roll, prevError_angle_roll = 0;
double integral_angle_roll = 0;
double kp_angle_roll = 5, ki_angle_roll = 0.001, kd_angle_roll = 0.01;
unsigned long lastTime_angle_roll;
float sampleTime_angle = 0.01;  // 100 Hz
float rateTarget_roll = 0;      // output → target laju (°/s)

double error_angle_pitch, prevError_angle_pitch = 0;
double integral_angle_pitch = 0;
float kp_angle_pitch = 5, ki_angle_pitch = 0.01, kd_angle_pitch = 0.01;
unsigned long lastTime_angle_pitch;
float rateTarget_pitch = 0;  // output → target laju (°/s)

// ===== Inner Loop (Rate PID) =====
double error_rate_roll, prevError_rate_roll = 0;
double integral_rate_roll = 0;
double kp_rate_roll = 1, ki_rate_roll = 0.01, kd_rate_roll = 0.04;
unsigned long lastTime_rate_roll;
float sampleTime_rate = 0.002;  // 500 Hz
double integral_limit = 30;     // batas integral anti-windup
double pwmOut_roll = 0;         // output → sinyal motor

double error_rate_pitch, prevError_rate_pitch = 0;
double integral_rate_pitch = 0;
float kp_rate_pitch = 1, ki_rate_pitch = 0.01, kd_rate_pitch = 0.05;
unsigned long lastTime_rate_pitch;
double pwmOut_pitch = 0;

// ===== Motor output (4 motor quad) =====
double pwm_1 = 0, pwm_2 = 0, pwm_3 = 0, pwm_4 = 0;

unsigned long lastSend = 0;
unsigned long interval = 220;  // kirim tiap 200ms

void setup() {
  Serial.begin(9600);
  Serial.println("test");

  tuner.begin();
  delay(1500);
  mpuSetup();
  motorSetup();
}

void loop() {
  bacaSensor();
  kirim_terimaData();
  motorControl();
  hitungPIDRateRoll(sensor_mpu.getGyroY(), hitungPIDAngleRoll(angleY));
  hitungPIDRatePitch(sensor_mpu.getGyroX(), hitungPIDAnglePitch(angleX));
  hitungPIDRateYaw(sensor_mpu.getGyroZ(), setPoint_yaw);

  // motorTest();
}

void mpuSetup() {
  Wire.begin(7, 6);
  sensor_mpu.begin(3, 2);
  sensor_mpu.upsideDownMounting = true;
  sensor_mpu.setFilterGyroCoef(0.96);
  Wire.beginTransmission(0x68);
  Wire.write(0x1A);
  Wire.write(0x04);
  Wire.endTransmission();
  sensor_mpu.calcOffsets();
  delay(1000);
}

void motorSetup() {
  ledcAttach(1, 1500, 8);
  ledcAttach(2, 1500, 8);
  ledcAttach(3, 1500, 8);
  ledcAttach(4, 1500, 8);
}

void bacaSensor() {
  sensor_mpu.update();
  angleY = -sensor_mpu.getAngleY();
  angleX = -sensor_mpu.getAngleX();
}

void motorControl() {
  int state = tuner.getMotorState();
  pwm_1 = constrain(throttle - pwmOut_roll + pwmOut_yaw + u1, 0, batas);
  pwm_2 = constrain(throttle + pwmOut_pitch - pwmOut_yaw + u3, 0, batas);
  pwm_3 = constrain(throttle + pwmOut_roll + pwmOut_yaw + u2, 0, batas);
  pwm_4 = constrain(throttle - pwmOut_pitch - pwmOut_yaw + u4, 0, batas);

  if (state == 1) {
    ledcWrite(1, pwm_1);  // Motor kanan (Right)
    ledcWrite(2, pwm_2);  // Motor kanan (Atas)
    ledcWrite(3, pwm_3);  // Motor kiri (Left)
    ledcWrite(4, pwm_4);  // Motor kanan (Bawah)
  } else {
    ledcWrite(1, 0);  // Motor kanan (Right)
    ledcWrite(2, 0);  // Motor kanan (Atas)
    ledcWrite(3, 0);  // Motor kiri (Left)
    ledcWrite(4, 0);  // Motor kanan (Bawah)
  }
}

void motorTest() {
  ledcWrite(1, 200);  // Motor kanan (Right)
  ledcWrite(3, 200);  // Motor kiri (Left)
}

void kirim_terimaData() {
  if (millis() - lastSend > interval) {
    tuner.sendAngle_roll(angleY);
    tuner.sendAngle_pitch(angleX);
    tuner.sendPWM_1(pwm_1);
    tuner.sendPWM_2(pwm_2);
    tuner.sendPWM_3(pwm_3);
    tuner.sendPWM_4(pwm_4);

    throttle = tuner.getThrottle();
    // kp_angle_yaw = tuner.getYawP();
    // ki_angle_yaw = tuner.getYawI();
    // kd_angle_yaw = tuner.getYawD();
    kp_angle_pitch = tuner.getPitchP();
    ki_angle_pitch = tuner.getPitchI();
    kd_angle_pitch = tuner.getPitchD();
    kp_angle_roll = tuner.getRollP();
    ki_angle_roll = tuner.getRollI();
    kd_angle_roll = tuner.getRollD();

    kp_rate_yaw = tuner.getYawInnerP();
    ki_rate_yaw = tuner.getYawInnerI();
    kd_rate_yaw = tuner.getYawInnerD();
    kp_rate_pitch = tuner.getPitchInnerP();
    ki_rate_pitch = tuner.getPitchInnerI();
    kd_rate_pitch = tuner.getPitchInnerD();
    kp_rate_roll = tuner.getRollInnerP();
    ki_rate_roll = tuner.getRollInnerI();
    kd_rate_roll = tuner.getRollInnerD();

    lastSend = millis();
  }
}

// ===== Outer Loop: Angle Control =====
float hitungPIDAngleRoll(float angleY) {
  unsigned long now = millis();
  float dt = (now - lastTime_angle_roll) / 1000.0;

  if (dt >= sampleTime_angle) {
    float error = setPoint_roll - angleY;

    float P = kp_angle_roll * error;
    integral_angle_roll += error * dt;

    // Anti-windup
    if (integral_angle_roll > integral_limit) integral_angle_roll = integral_limit;
    if (integral_angle_roll < -integral_limit) integral_angle_roll = -integral_limit;

    float I = ki_angle_roll * integral_angle_roll;
    float D = kd_angle_roll * ((error - prevError_angle_roll) / dt);

    rateTarget_roll = P + I + D;

    // Batas rate target
    if (rateTarget_roll > 200) rateTarget_roll = 200;
    if (rateTarget_roll < -200) rateTarget_roll = -200;

    prevError_angle_roll = error;
    lastTime_angle_roll = now;
  }

  return rateTarget_roll;
}

float hitungPIDAnglePitch(float angleX) {
  unsigned long now = millis();
  float dt = (now - lastTime_angle_pitch) / 1000.0;

  if (dt >= sampleTime_angle) {
    float error = setPoint_pitch - angleX;

    float P = kp_angle_pitch * error;
    integral_angle_pitch += error * dt;
    // Anti-windup
    if (integral_angle_pitch > integral_limit) integral_angle_pitch = integral_limit;
    if (integral_angle_pitch < -integral_limit) integral_angle_pitch = -integral_limit;

    float I = ki_angle_pitch * integral_angle_pitch;
    float D = kd_angle_pitch * ((error - prevError_angle_pitch) / dt);

    rateTarget_pitch = P + I + D;

    if (rateTarget_pitch > 200) rateTarget_pitch = 200;
    if (rateTarget_pitch < -200) rateTarget_pitch = -200;

    prevError_angle_pitch = error;
    lastTime_angle_pitch = now;
  }

  return rateTarget_pitch;
}

void hitungPIDRateYaw(float gyroZ, float setPoint_yaw) {
  unsigned long now = millis();
  float dt = (now - lastTime_rate_yaw) / 1000.0;

  if (dt >= sampleTime_rate) {
    float error = setPoint_yaw - gyroZ;

    float P = kp_rate_yaw * error;
    integral_rate_yaw += error * dt;

    // Anti-windup
    if (integral_rate_yaw > integral_limit) integral_rate_yaw = integral_limit;
    if (integral_rate_yaw < -integral_limit) integral_rate_yaw = -integral_limit;

    float I = ki_rate_yaw * integral_rate_yaw;
    float D = kd_rate_yaw * ((error - prevError_rate_yaw) / dt);

    pwmOut_yaw = P + I + D;

    if (pwmOut_yaw > 200) pwmOut_yaw = 200;
    if (pwmOut_yaw < -200) pwmOut_yaw = -200;

    prevError_rate_yaw = error;
    lastTime_rate_yaw = now;
  }
}


// ===== Inner Loop: Rate Control =====
void hitungPIDRateRoll(float gyroY, float rateTarget_roll) {
  unsigned long now = millis();
  float dt = (now - lastTime_rate_roll) / 1000.0;

  if (dt >= sampleTime_rate) {
    float error = rateTarget_roll - gyroY;

    float P = kp_rate_roll * error;
    integral_rate_roll += error * dt;

    // Anti-windup
    if (integral_rate_roll > integral_limit) integral_rate_roll = integral_limit;
    if (integral_rate_roll < -integral_limit) integral_rate_roll = -integral_limit;

    float I = ki_rate_roll * integral_rate_roll;
    float D = kd_rate_roll * ((error - prevError_rate_roll) / dt);

    pwmOut_roll = P + I + D;

    if (pwmOut_roll > 200) pwmOut_roll = 200;
    if (pwmOut_roll < -200) pwmOut_roll = -200;

    prevError_rate_roll = error;
    lastTime_rate_roll = now;
  }
}

void hitungPIDRatePitch(float gyroX, float rateTarget_pitch) {
  unsigned long now = millis();
  float dt = (now - lastTime_rate_pitch) / 1000.0;

  if (dt >= sampleTime_rate) {
    float error = rateTarget_pitch - gyroX;

    float P = kp_rate_pitch * error;
    integral_rate_pitch += error * dt;
    // Anti-windup
    if (integral_rate_pitch > integral_limit) integral_rate_pitch = integral_limit;
    if (integral_rate_pitch < -integral_limit) integral_rate_pitch = -integral_limit;

    float I = ki_rate_pitch * integral_rate_pitch;
    float D = kd_rate_pitch * ((error - prevError_rate_pitch) / dt);

    pwmOut_pitch = P + I + D;

    if (pwmOut_pitch > 200) pwmOut_pitch = 200;
    if (pwmOut_pitch < -200) pwmOut_pitch = -200;

    prevError_rate_pitch = error;
    lastTime_rate_pitch = now;
  }
}

void motorState() {
  int state = tuner.getMotorState();
  Serial.println(state);
  if (state == 0) {
    pwm_1 = 0;
    pwm_2 = 0;
    pwm_3 = 0;
    pwm_4 = 0;
    integral_limit = 0;
  } else {
    integral_limit = 30;
  }
}

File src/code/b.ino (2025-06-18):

#include <puc_v2.h>
#include <MPU6050_light.h>
#include "ArduPID.h"
#include <Preferences.h>

ArduPID pitch_pid;
ArduPID roll_pid;
MPU6050 sensor_mpu(Wire);
puc myController;
Preferences pref;

double pwm_0, pwm_1, pwm_2, pwm_3 = 0;
double angle_x, angle_y, angle_x_filtered, angle_y_filtered = 0;
double pitch_out, roll_out, set_point = 0;
double dataLY, dataLX, dataRY = 0;

void setup() {
  Wire.begin(7, 6);

  Serial.begin(9600);
  sensor_mpu.begin(1, 3);
  sensor_mpu.upsideDownMounting = false;
  sensor_mpu.setFilterGyroCoef(0.995);
  Wire.beginTransmission(0x68);
  Wire.write(0x1A);
  Wire.write(0x05);
  Wire.endTransmission();
  myController.begin("ESP32_WebServer", "123456789", IPAddress(192, 168, 4, 1));
  pref.begin("kalibrasiMPU", true);
  float ax = pref.getFloat("ax");
  float ay = pref.getFloat("ay");
  float az = pref.getFloat("az");
  float gx = pref.getFloat("gx");
  float gy = pref.getFloat("gy");
  float gz = pref.getFloat("gz");
  pref.end();
  sensor_mpu.setAccOffsets(ax, ay, az);
  sensor_mpu.setGyroOffsets(gx, gy, gz);
  Serial.println("MPU READY");

  pitch_pid.begin(&angle_x, &pitch_out, &dataLX, 1, 0, 0.2);
  pitch_pid.setOutputLimits(-127.5, 127.5);
  pitch_pid.setWindUpLimits(-10, 10);

  roll_pid.begin(&angle_y, &roll_out, &dataLY, 1, 0, 0.15);
  roll_pid.setOutputLimits(-127.5, 127.5);
  roll_pid.setWindUpLimits(-16, 16);

  ledcSetup(0, 1500, 8);
  ledcSetup(1, 1500, 8);
  ledcSetup(2, 1500, 8);
  ledcSetup(3, 1500, 8);
  ledcAttachPin(1, 0);
  ledcAttachPin(2, 1);
  ledcAttachPin(3, 2);
  ledcAttachPin(4, 3);
}

void loop() {
  myController.DNS_RUN();
  sensor_mpu.update();
  if (myController.device_status()) {
    dataRY = map(myController.getRX(), -128, 127, 0, 200);
    dataLY = map(myController.getLY(), 0, 127, 0, 25);
    dataLX = map(myController.getLX(), 0, 127, 0, 25);
    angle_x = round(-sensor_mpu.getAngleX());
    angle_y = round(-sensor_mpu.getAngleY());

    pitch_pid.compute();
    roll_pid.compute();

    pwm_0 = dataRY + pitch_out + roll_out;  // pwm_0
    pwm_1 = dataRY + pitch_out - roll_out;  // pwm_1
    pwm_2 = dataRY - pitch_out + roll_out;  // pwm_2
    pwm_3 = dataRY - pitch_out - roll_out;

    pwm_0 = constrain(pwm_0, 0, 255);
    pwm_1 = constrain(pwm_1, 0, 255);
    pwm_2 = constrain(pwm_2, 0, 255);
    pwm_3 = constrain(pwm_3, 0, 255);

    // ledcWrite(0, pwm_0);
    // ledcWrite(1, pwm_1);
    // ledcWrite(2, pwm_2);
    // ledcWrite(3, pwm_3);

    // Cetak data PID dan PWM
    // Serial.print("AngleX: ");
    Serial.print(100);
    Serial.print(",");
    Serial.print(angle_y, 2);
    Serial.print(",");
    Serial.print(-100);
    Serial.print(",");
    Serial.println(angle_x, 2);

  } else {
    dataLX = 0;
    dataLY = 0;
    dataRY = 0;
    angle_y = 0;
    angle_x = 0;
    pitch_out = 0;
    roll_out = 0;

    pwm_0 = 0;
    pwm_1 = 0;
    pwm_2 = 0;
    pwm_3 = 0;

    ledcWrite(0, 0);
    ledcWrite(1, 0);
    ledcWrite(2, 0);
    ledcWrite(3, 0);
  }
}

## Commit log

2025-03-28 Update 18-03-2025.txt
    Tambahan PID dari fikri alif
2025-04-09 folder khusus riset mandiri
    membuat folder khusus riset mandiri, kemudian di dalamnya saya masukan pengenalan sedikit tentang mpu-6050
